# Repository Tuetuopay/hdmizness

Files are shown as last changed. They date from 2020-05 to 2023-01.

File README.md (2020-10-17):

# hdmizness

A business card that runs Linux and that has an HDMI output.

## Project layout

```
.
+- documentation       - docs for various chips and boards used
+- graphics            - various graphic files used for the hardware design
+- hardware            - home of the hardware design files
|  `- licheedmi        - PoC board that leverages a Lichee Pi Nano to test the concept
|                        of a pcb-only hdmi female connector
`- software            - everything related to the software running on those boards
```

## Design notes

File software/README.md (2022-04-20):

# HDMIzness software

The business card runs a plain Buildroot build, with proper patches.

## Compiling

You need a working compiler, along with the required deps for a buildroot build. On Debian 11 this
would be:

- build-essentials
- rsync

The following commands assume you are in the current directory (`software/` from the root of the
repo):

```
# Download buildroot
git submodule update --init

# Create config (ignore warnings about the Doom WAD)
make -C buildroot BR2_EXTERNAL=.. hdmizness_defconfig

# Build
make -C buildroot BR2_EXTERNAL=.. -j$(nproc)
```

A full build takes 30 minutes on a Xeon E-2246G.

Build artifacts are now present in `buildroot/output/images`, with a full image ready to be flashed
on the card as `buildroot/output/images/flash.bin`.

## Flashing

Programming the card is done over USB with Allwinner's FEL mode. The tool to flash has been built
by buildroot, and is present in the host tool directory (`buildroot/output/host/bin`) as
`sunxi-fel`.

First, the card needs to be put in FEL mode.

- If it has not been programmed before, it will boot to FEL mode once powered up.
- If it already has a working image, it needs to "fail" to boot. The easiest way is to short one of
  the SPI pins of the flash to ground (a simple DuPont jumper works fine), and to press the onboard
  Reset button. The SoC will fail to read the flash, and fallback to FEL mode.

FEL can be confirmed by listing the USB devices:

```
$ lsusb -d 1f3a:efe8
Bus 001 Device 018: ID 1f3a:efe8 Allwinner Technology sunxi SoC OTG connector in FEL/flashing mode
```

With FEL found, the card can be flashed using `sunxi-fel` (note that it needs to be run as root,
unless udev rules have been setup):

```
# buildroot/output/host/bin/sunxi-fel -v -p spiflash-write 0 buildroot/output/images/flash.bin
```

Once finished, reset the card with the onboard button. After a few seconds, the onboard LED should
switch from a solid red to a solid blue (v1 with NXP TDA HDMI transmitter) or green (v2 with Lattice
SiI HDMI transmitter). Then, it should turn white to indicate a successful Linux boot.

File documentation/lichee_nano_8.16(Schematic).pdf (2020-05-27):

LCD | DDR | CSI

## SDC0

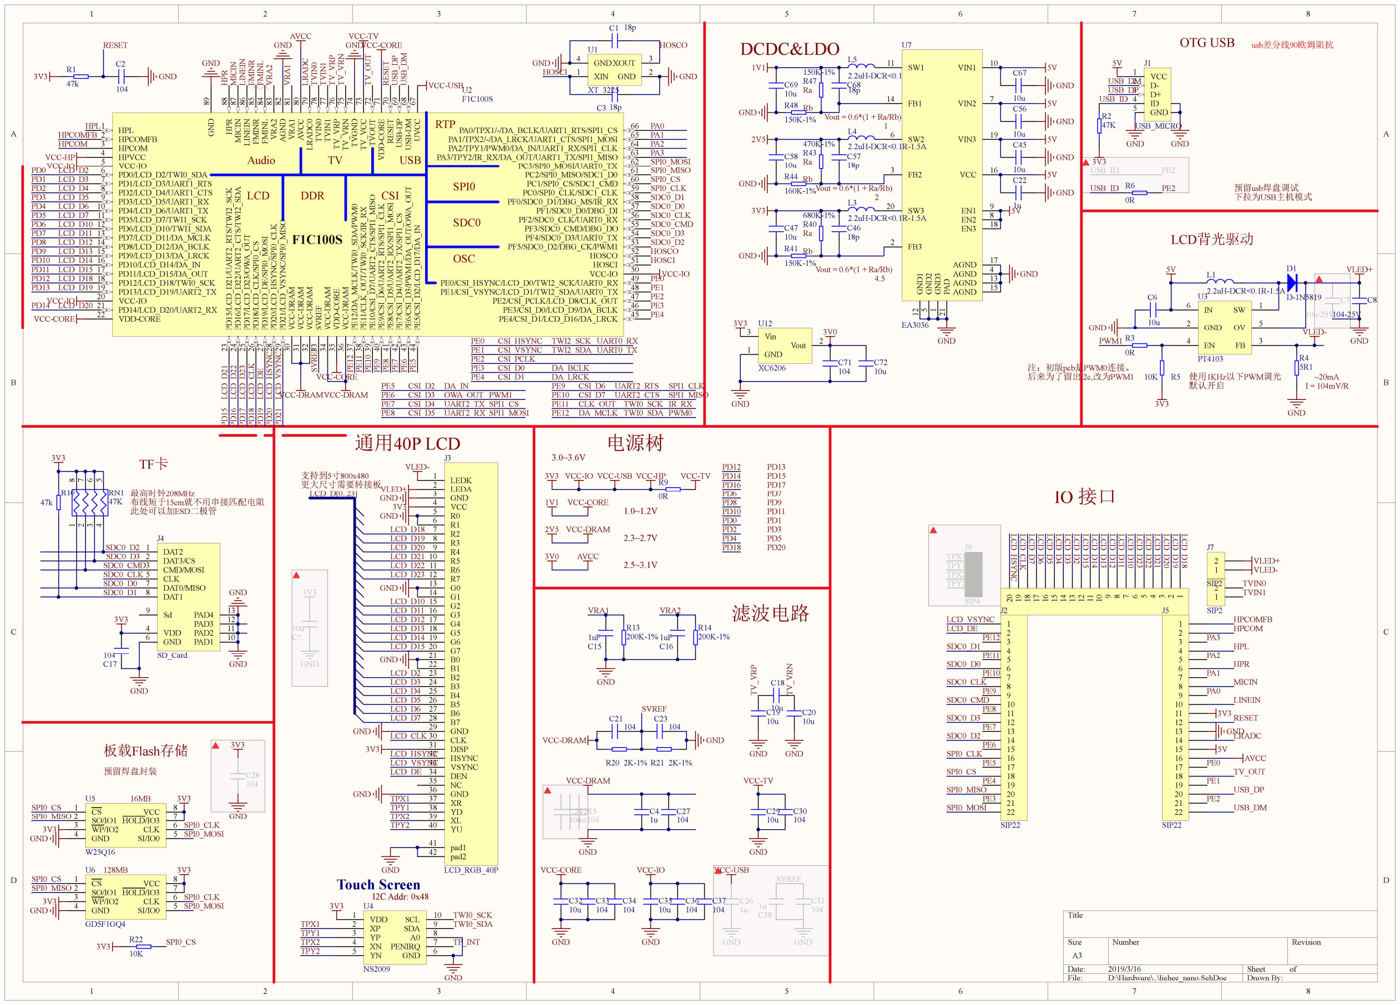
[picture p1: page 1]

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
Title

Size | Number | | Revision
A3
Date: | 2019/3/16 | Sheet | of
File: | D:\Hardware\..\lichee_nano.SchDoc | Drawn By:

HPL 1
HPCOMFB 2
HPCOM 3
HPVCC 4
VCC-IO 5
PD0/LCD_D2/TWI0_SDA 6
PD1/LCD_D3/UART1_RTS 7
PD2/LCD_D4/UART1_CTS 8
PD3/LCD_D5/UART1_RX 9
PD4/LCD_D6/UART1_TX 10
PD5/LCD_D7/TWI1_SCK 11
PD6/LCD_D10/TWI1_SDA 12
PD7/LCD_D11/DA_MCLK 13
PD8/LCD_D12/DA_BCLK 14
PD9/LCD_D13/DA_LRCK 15
PD10/LCD_D14/DA_IN 16
PD11/LCD_D15/DA_OUT 17
PD12/LCD_D18/TWI0_SCK 18
PD13/LCD_D19/UART2_TX 19
VCC-IO 20
PD14/LCD_D20/UART2_RX 21
VDD-CORE 22 | PD¹⁵/LCD_D²¹/UART²_RTS/TWI2_SCK 23 PD¹⁶/LCD_D²²/UART²_CTS/TWI2_SDA 24 PD¹⁷/LCD_D²³/OWA_OUT 25 PD¹⁸/LCD_CLK/SPI0_CS 26 PD¹⁹/LCD_DE/SPI0_MOSI 27 PD²⁰/LCD_HSYNC/SPI0_CLK 28 PD²¹/LCD_VSYNC/SPI0_MISO 29 VCC⁻DRAM 30 VCC⁻DRAM 31 VCC⁻DRAM 32 SVREF 33 VCC⁻DRAM 34 VDD⁻CORE 35 VCC⁻DRAM 36 PE¹²/DA_MCLK/TWI0_SDA/PWM⁰ 37 PE¹¹/CLK_OUT/TWI0_SCK/IR_RX 38 PE¹⁰/CSI_D⁷/UART²_CTS/SPI1_MISO 39 PE⁹/CSI_D⁶/UART²_RTS/SPI1_CLK 40 PE⁸/CSI_D⁵/UART²_RX/SPI1_MOSI 41 PE⁷/CSI_D⁴/UART²_TX/SPI1_CS 42 PE⁶/CSI_D³/PWM¹/DA_OUT/OWA_OUT 43 PE⁵/CSI_D²/LCD_D¹⁷/DA_IN 44
PE4/CSI_D1/LCD_D16/DA_LRCK | 45 PE3/CSI_D0/LCD_D9/DA_BCLK | 46 PE2/CSI_PCLK/LCD_D8/CLK_OUT | 47 PE1/CSI_VSYNC/LCD_D1/TWI2_SDA/UART0_TX | 48 PE0/CSI_HSYNC/LCD_D0/TWI2_SCK/UART0_RX | 49 VCC-IO | 50 HOSCI | 51 HOSCO | 52 PF5/SDC0_D2/DBG_CK/PWM1 | 53 PF4/SDC0_D3/UART0_TX | 54 PF3/SDC0_CMD/DBG_DO | 55 PF2/SDC0_CLK/UART0_RX | 56 PF1/SDC0_D0/DBG_DI | 57 PF0/SDC0_D1/DBG_MS/IR_RX | 58 PC0/SPI0_CLK/SDC1_CLK | 59 PC1/SPI0_CS/SDC1_CMD | 60 PC2/SPI0_MISO/SDC1_D0 | 61 PC3/SPI0_MOSI/UART0_TX | 62 PA3/TPY2/IR_RX/DA_OUT/UART1_TX/SPI1_MISO | 63 PA2/TPY1/PWM0/DA_IN/UART1_RX/SPI1_CLK | 64 PA1/TPX2/-/DA_LRCK/UART1_CTS/SPI1_MOSI | 65 PA0/TPX1/-/DA_BCLK/UART1_RTS/SPI1_CS | 66 UVCC ⁶⁷ USB⁻DM ⁶⁸ USB⁻DP ⁶⁹ RESET ⁷⁰ VDD⁻CORE ⁷¹ TVOUT ⁷² TV_VCC ⁷³ TVGND ⁷⁴ TV_VRN ⁷⁵ TV_VRP ⁷⁶ TVIN¹ ⁷⁷ TVIN⁰ ⁷⁸ LRADC⁰ ⁷⁹ AVCC ⁸⁰ VRA¹ ⁸¹ AGND ⁸² VRA² ⁸³ FMINL ⁸⁴ FMINR ⁸⁵ LINEIN ⁸⁶ MICIN ⁸⁷ HPR ⁸⁸ GND ⁸⁹

## OSC

## SPI0

## RTP

Audio | TV | USB

## F1C100S

U2
F1C100S

LEDK 1
LEDA 2
GND 3
VCC 4
R0 5
R1 6
R2 7
R3 8
R4 9
R5 10
R6 11
R7 12
G0 13
G1 14
G2 15
G3 16
G4 17
G5 18
G6 19
G7 20
B0 21
B1 22
B2 23
B3 24
B4 25
B5 26
B6 27
B7 28
GND 29
CLK 30
DISP 31
HSYNC 32
VSYNC 33
DEN 34
NC 35
GND 36
XR 37
YD 38
XL 39
YU 40

pad1 41
pad2 42

J3

LCD_RGB_40P

LCD_D2
LCD_D3
LCD_D4
LCD_D5
LCD_D6
LCD_D7

LCD_D10
LCD_D11
LCD_D12
LCD_D13
LCD_D14
LCD_D15

LCD_D18
LCD_D19
LCD_D20
LCD_D21
LCD_D22
LCD_D23

LCD_D[0..23] GND

3V3

GND

C?

10u

LCD_CLK

LCD_DE

LCD_HSYNC
LCD_VSYNC

TPX1

TPX2

TPY1

TPY2

GND

GND

VLED+

VLED-

# 通用40P LCD

GND

GND

GND

3V3

3V3

GND

支持到5寸800x480
更大尺寸需要转接板

LCD_D2
LCD_D3
LCD_D4
LCD_D5
LCD_D6
LCD_D7
LCD_D10
LCD_D11
LCD_D12
LCD_D13
LCD_D14
LCD_D15
LCD_D18
LCD_D19
LCD_D20 | LCD_D²¹ LCD_D²² LCD_D²³ LCD_CLK LCD_DE LCD_HSYNC LCD_VSYNC

VCC-IO

VCC-IO

VCC-IO

VCC-CORE

VCC-CORE

VCC-DRAMVCC-DRAM SVREF

VCC-CORE RESET USB_DP USB_DMGND

VCC-HP

HPL | HPR MICIN LINEIN FMINR FMINL VRA² | VRA¹ AVCCLRADC TVIN⁰ TVIN¹ TV_VRP TV_VRN

VCC-TVTV_OUT

PE0
PE1
PE2
PE3

PE4 PE¹² PE¹¹ PE¹⁰ PE⁹ PE⁸ PE⁷ PE⁶ PE⁵

HOSCO
HOSCI

SDC0_D0

SDC0_D1

SDC0_D2

SDC0_D3

SDC0_CLK
SDC0_CMD

SPI0_CLK

SPI0_CS

SPI0_MISO

SPI0_MOSI

HPCOMFB
HPCOM
XIN 1 | GND | 2
XOUT | 3 GND 4

U1

XT_3225

GND
GND

C3 18p

C1 18p

HOSCO

HOSCI

SDC0_CMD
SDC0_CLK
SDC0_D0
SDC0_D1

SDC0_D2
SDC0_D3

GND

GND

3V3

C17

104 ¹

2

34 58
7

6
RN1
47K

R10
47k

3V3

最高时钟208MHz
布线短于15cm就不用串接匹配电阻
此处可以加ESD二极管

## TF卡

GND

CS 1
SO/IO1 2
WP/IO2 3
GND 4 | SI/IO0 | 5
| CLK | 6
HOLD/IO3 | 7
VCC | 8

U5

W25Q16

SPI0_MISO

SPI0_MOSI

SPI0_CLK

SPI0_CS

CS 1
SO/IO1 2
WP/IO2 3
GND 4 | SI/IO0 | 5
| CLK | 6
HOLD/IO3 | 7
VCC | 8

U6

GD5F1GQ4

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
3V3 | SPI0_CS

16MB

128MB

## 板载Flash存储

预留焊盘封装

# DCDC&LDO

SW 1

GND 2

FB | 3 EN 4
OV | 5

IN 6

U3

PT4103

L1
2.2uH-DCR<0.1R-1.5A
C6

10u GND

D1

D-1N5819 C7

10u-25V

C8

| 104-25V VLED+

GND

10K R5
I = 104mV/R

R4
5R1

GND

VLED-

使用1KHz以下PWM调光 | ~20mA

## LCD背光驱动

5V

PWM1 R3
0R

R2
47K

usb差分线90欧姆阻抗

VCC 1
D- 2
D+ 3
ID 4
GND 5

J1

USB_MICRO

GND GND

USB_ID

预留usb焊盘调试
下拉为USB主机模式

# 电源树

3V3 VCC-IO

GND | GND

VCC-TV

1V1 VCC-CORE
1.0~1.2V

3.0~3.6V

VCC-USB

VCC-USB

2V5 VCC-DRAM
2.3~2.7V

3V0 AVCC
2.5~3.1V

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
PD10
PD11
PD12
PD13
PD14 | PD¹⁵ PD¹⁶ PD¹⁷ PD¹⁸ PD¹⁹ PD²⁰ PD²¹
PD0 | PD1
PD2 | PD3
PD4 | PD5
PD6 | PD7
PD8 | PD9
PD10 | PD11
PD12 | PD13
PD14 | PD15
PD16 | PD17

C2

104

3V3 | GND

RESET

GND

C15

1uF

R13
200K-1%
VRA1 | VRA2

C16

1uF

R14
200K-1%

R20 2K-1% R21 2K-1%

C21
104

C23
104
VCC-DRAM | GND

SVREF

SVREF

C31
104 C38

1u

GND

VCC-DRAM

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
VCC-CORE

C32
10u

C33
104

C34
104

GND

VCC-IO

C35
10u

C36
104

C37
104

GND

VCC-TV

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
GND | GND TV_VRP | TV_VRN

## OTG USB

# 滤波电路

# IO 接口

USB_DP

USB_DM

VCC-HP

R1
47k

R9
0R

SPI0_MISO

SPI0_MOSI

SPI0_CLK

SPI0_CS

1V1 | 5V

L5

# 2.2uH-DCR<0.1R-1.5A GND³

1

FB3 2

FB2 3

AGND 4 GND²

5

SW2 6

VIN2 | 7
EN2 | 8
EN1 | 9
VIN1 | 10 SW1 11 | GND¹ 12
AGND | 13

FB1 14

AGND | 15
VCC | 16
AGND | 17
EN3 | 18
VIN3 | 19
SW3 20 | PAD 21

U7

EA3036

R47

150K-1%
GND

C67

10u

C68 18p C69
10u Ra
5V Rb GND
GND Vout = 0.6*(1 + Ra/Rb)

C56

10u

R48
150K-1%
1
2V5 | 5V

L4
2.2uH-DCR<0.1R-1.5A
R43

470K-1%
GND

C45

10u

C57
18p

C58
10u Ra
5V Rb GND | Vout = 0.6*(1 + Ra/Rb) | GND
C22

1u

R44
160K-1%
2
3V3 | 5V

L3
2.2uH-DCR<0.1R-1.5A
R40

680K-1%
C46
18p

C47
10u Ra

Rb GND

R41
150K-1%
GND Vout = 0.6*(1 + Ra/Rb) 4.5

GND

3V0

C71
104

Vin 3

GND 1

Vout 2

U12

XC6206

3V3

C72
10u

GND

C26
1u

GND

VCC-USB

3V3

C28
104

GND

3V3 20 | 119 | 218 | 317 | 416 | 515 | 614 | 713 | 812 | 91110

J8

# SIP20LCD_HSYNC LCD_CLK

LCD_DE

LCD_VSYNC | LCD_D7 LCD_D6 LCD_D5 LCD_D4 LCD_D3 LCD_D2 LCD_D15 LCD_D14 LCD_D13 LCD_D12 LCD_D11 LCD_D10 LCD_D23 LCD_D22 LCD_D21 LCD_D20 LCD_D19 LCD_D18 PD18 | PD20

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
PE10
PE11
PE12

CSI_HSYNC TWI2_SCK UART0_RX CSI_VSYNC TWI2_SDA UART0_TX CSI_PCLK
CSI_D0
CSI_D1
CSI_D2
CSI_D3
CSI_D4
CSI_D5

CSI_D6
CSI_D7

DA_MCLK

CLK_OUT

DA_BCLK
DA_LRCK
DA_IN
OWA_OUT
UART2_TX SPI1_CS
UART2_RX SPI1_MOSI

UART2_RTS SPI1_CLK
UART2_CTS SPI1_MISO
TWI0_SCK
TWI0_SDA

IR_RX
PWM0

3V3

默认开启

PA0
PA1
PA2
PA3

USB_ID R6
0R

PE2

USB_ID | PE2

PE5

PE6

PE7

PE8

PE9

PE10

PE11

PE12

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
SDC0_D0

SDC0_D1

SDC0_D2

SDC0_D3

SDC0_CLK

SDC0_CMD

SPI0_CLK

SPI0_CS

SPI0_MISO

SPI0_MOSI

HPL

HPCOMFB
HPCOM

RESET

USB_DP

USB_DM

HPR

MICIN

LINEIN

AVCC

LRADC

TVIN0
TVIN1

TV_OUT

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
SIP22

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
SIP22

DAT2 1
DAT3/CS 2
CMD/MOSI 3

VDD 4

CLK 5

GND 6

DAT0/MISO 7
DAT1 8

Sd 9

PAD1 | 10 PAD2 | 11 PAD3 | 12 PAD4 | 13

J4

SD_Card

1

2

J6

SIP2

1

2

J7

SIP2

VLED+
VLED-

1

2

3

4

J9

SIP4

TPX1

TPX2

TPY1

TPY2

PWM1

注：初版pcb是PWM0连接。
后来为了留出i2c,改为PWM1

# Touch Screen

TP_INT

I2C Addr: 0x48

VDD 1
XP 2
YP 3
XN 4
YN 5 | GND | 6
| PENIRQ | 7
| A0 | 8
SDA | 9
SCL | 10

U4

NS2009

3V3

TPX1
TPY1
TPX2

GND

TPY2

TWI0_SCK
TWI0_SDA

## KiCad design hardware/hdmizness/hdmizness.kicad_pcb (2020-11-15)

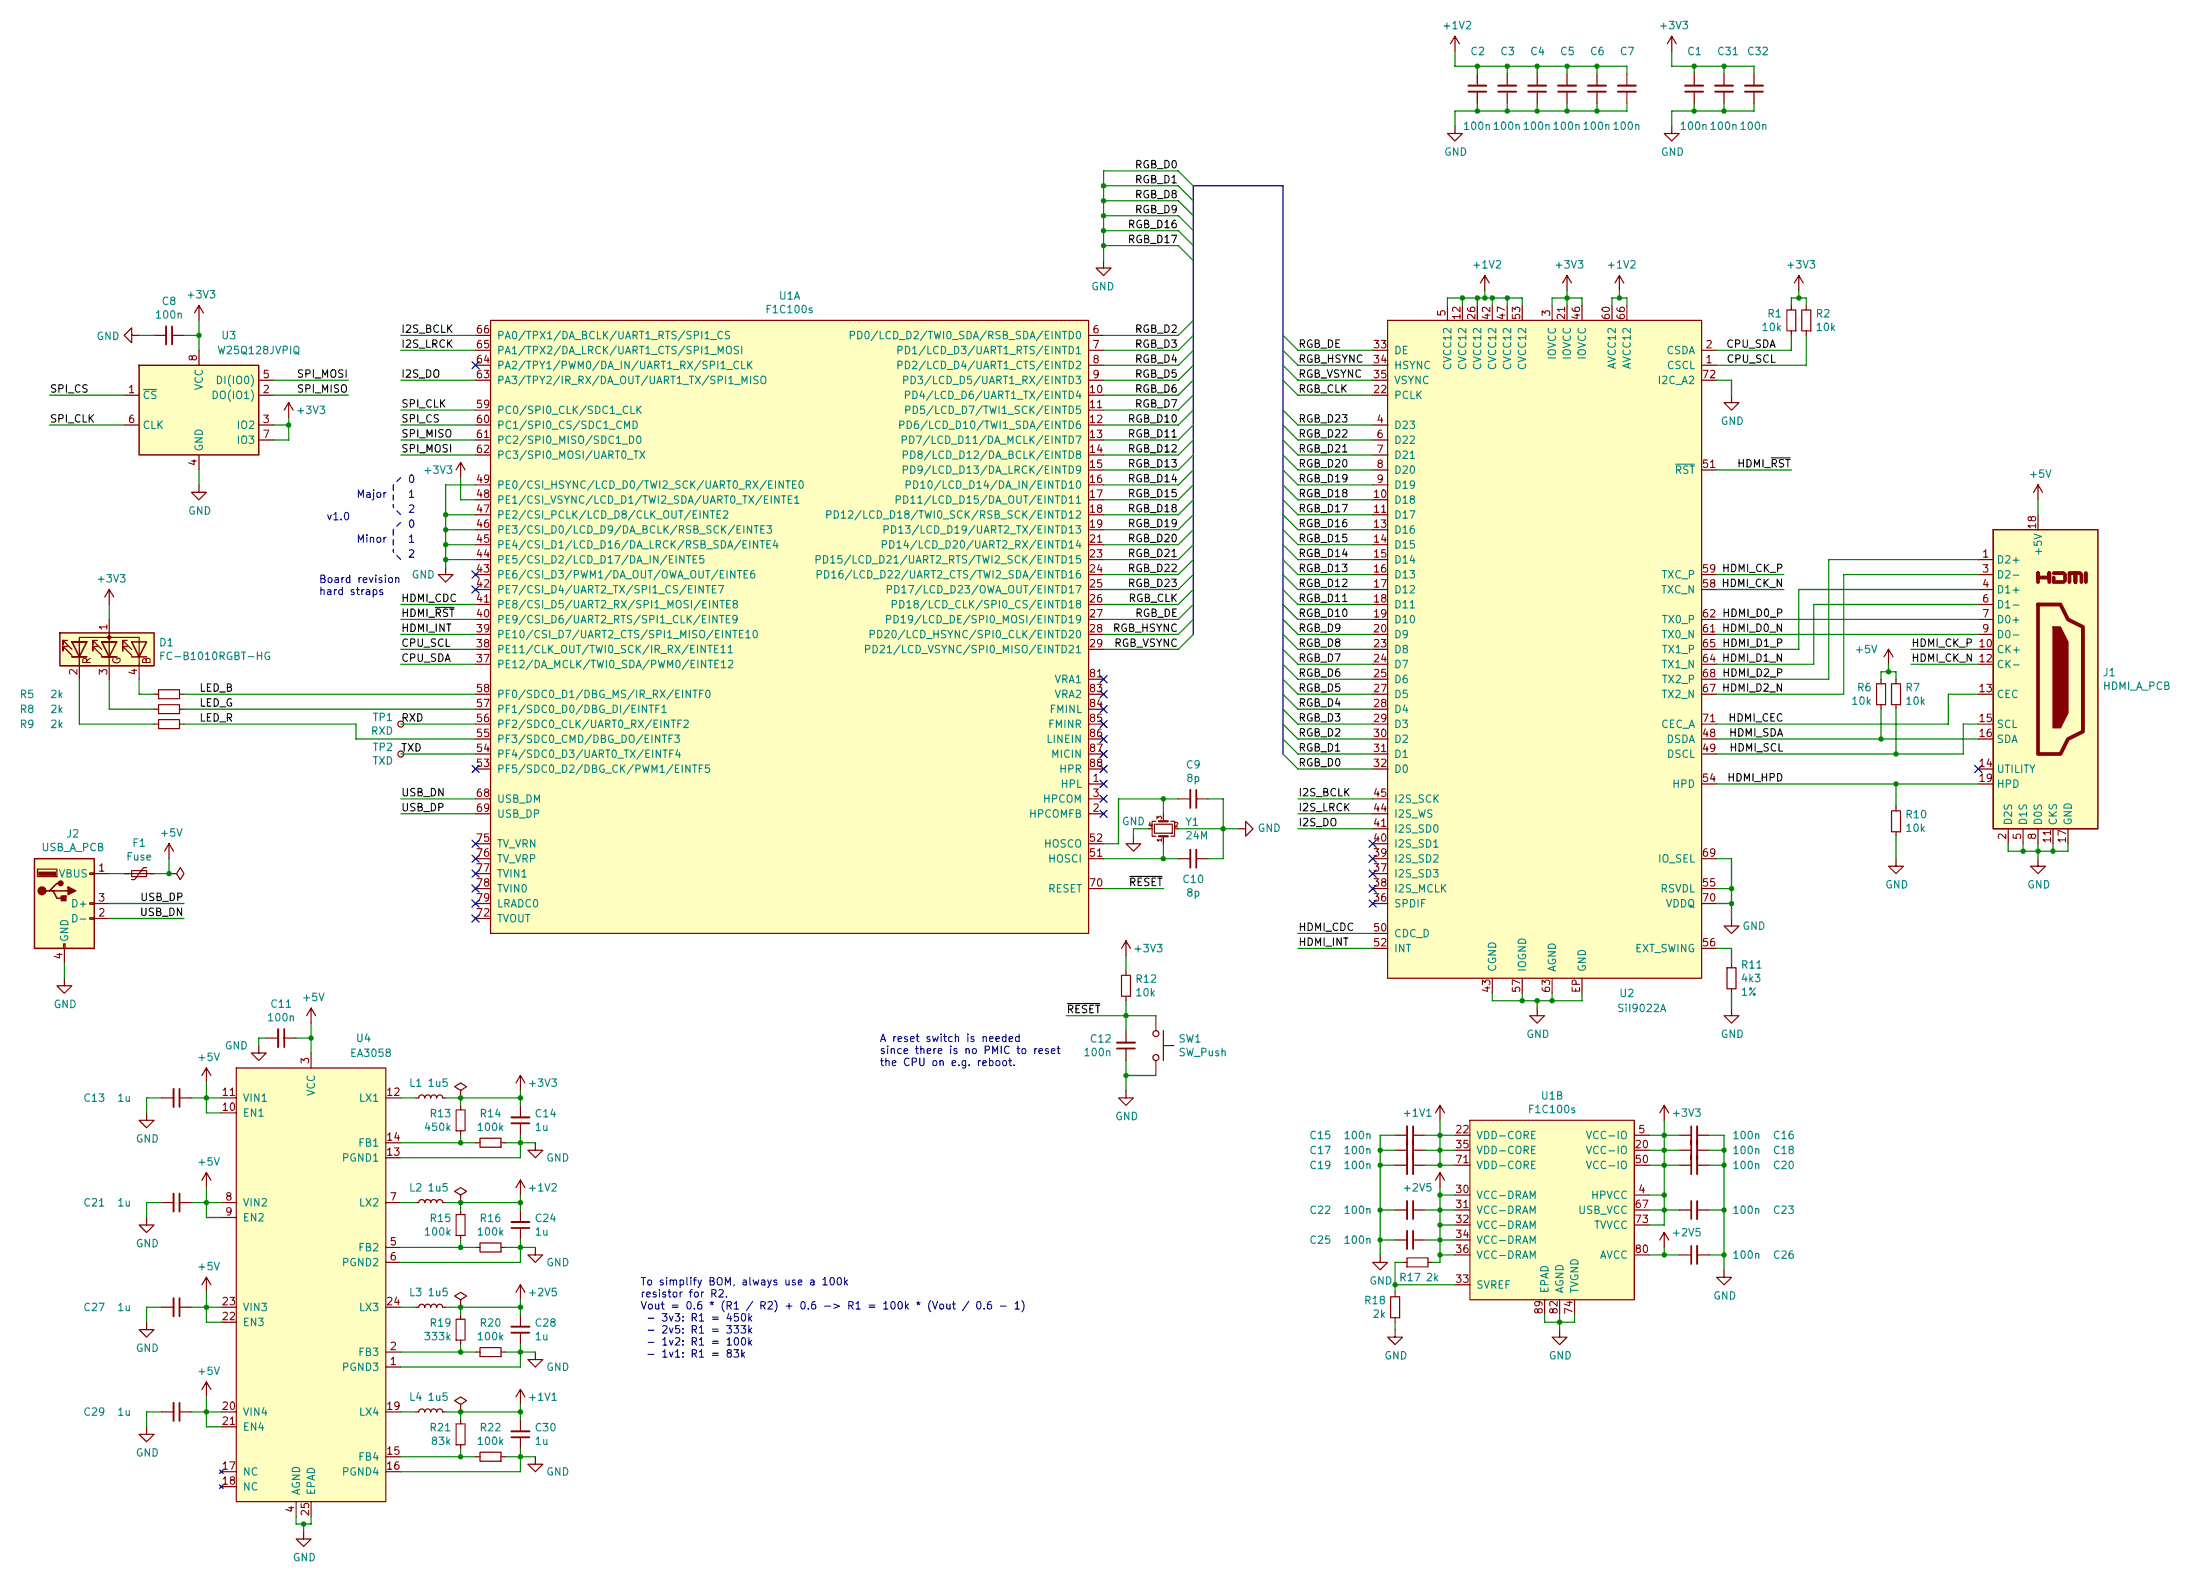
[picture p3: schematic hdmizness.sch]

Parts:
C1, C2, C3, C4, C5, C6, C7, C8, C11, C12, C15, C16, C17, C18, C19, C20, C22, C23, C25, C26, C31, C32: 100n; C_0402_1005Metric; MFR P/N CL05B104KO5NNNC; LCSC P/N C1525
C9, C10: 8p; C_0402_1005Metric; MFR P/N CL05C080CB5NNNC; LCSC P/N C318586
C13, C14, C21, C24, C27, C28, C29, C30: 1u; C_0402_1005Metric; MFR P/N CL05A105KQ5NNNC; LCSC P/N C107372
D1: FC-B1010RGBT-HG; PLCC1010
F1: Fuse; Fuse_0603_1608Metric; MFR P/N 06H1100D; LCSC P/N C182303
J1: HDMI_A_PCB
J2: USB_A_PCB
L1, L2, L3, L4: 1u5; L_Vishay_IHHP-0806; MFR P/N CIGT201610UM1R5MNE; LCSC P/N C307630
R1, R2, R6, R7, R10, R12: 10k; R_0402_1005Metric; MFR P/N CR-02FL6---10K; LCSC P/N C406733
R5, R8, R9, R17, R18: 2k; R_0402_1005Metric; MFR P/N RC-02W2001FT; LCSC P/N C304583
R11: 4k3; R_0402_1005Metric; Tolerance 1%; MFR P/N CR-02FL6---10K; LCSC P/N C406733
R13: 450k; R_0402_1005Metric; MFR P/N 0402WGF4503TCE; LCSC P/N C407681
R14, R16, R20, R22: 100k; R_0402_1005Metric; MFR P/N RC-02W1003FT; LCSC P/N C258090
R15: 100k; R_0402_1005Metric; MFR P/N WR04X2003FTL; LCSC P/N C305297
R19: 333k; R_0402_1005Metric; MFR P/N WR04X3323FTL; LCSC P/N C172051
R21: 83k; R_0402_1005Metric; MFR P/N RC-02W8202FT; LCSC P/N C304638
SW1: SW_Push; 1TS028A-2400-0603-CT; MFR P/N 1TS028A-2400-0603-CT; LCSC P/N C481994
TP1: RXD; TestPoint_Pad_1.0x1.0mm
TP2: TXD; TestPoint_Pad_1.0x1.0mm
U1: F1C100s; QFN-88_EP_10x10_Pitch0.4mm
U2: SiI9022A; QFN-72-1EP_10x10mm_P0.5mm_EP4.7x4.7mm_ThermalVias
U3: W25Q128JVPIQ; WSON-8-1EP_6x5mm_P1.27mm_EP3.4x4.3mm; MFR P/N W25Q128JVPIQ; LCSC P/N C190862
U4: EA3058; QFN-24-1EP_4x4mm_P0.5mm_EP2.6x2.6mm; MFR P/N EA3058QDR; LCSC P/N C575412
Y1: 24M; Crystal_SMD_2016-4Pin_2.0x1.6mm; MFR P/N CN4024M00009T8188011; LCSC P/N C708986

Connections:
+1V1: C15.1, C17.1, C19.1, C30.2, L4.2, R21.2, U1.22 (VDD-CORE), U1.35 (VDD-CORE), U1.71 (VDD-CORE)
+1V2: C2.2, C3.2, C4.2, C5.2, C6.2, C7.2, C24.2, L2.2, R15.2, U2.5 (CVCC12), U2.12 (CVCC12), U2.26 (CVCC12), U2.42 (CVCC12), U2.47 (CVCC12), U2.53 (CVCC12), U2.60 (AVCC12), U2.66 (AVCC12)
+2V5: C22.1, C25.1, C26.1, C28.2, L3.2, R17.2, R19.2, U1.30 (VCC-DRAM), U1.31 (VCC-DRAM), U1.32 (VCC-DRAM), U1.34 (VCC-DRAM), U1.36 (VCC-DRAM), U1.80 (AVCC)
+3V3: C1.2, C8.1, C14.2, C16.1, C18.1, C20.1, C23.1, C31.2, C32.2, D1.1 (A), L1.2, R1.2, R2.2, R12.2, R13.2, U1.4 (HPVCC), U1.5 (VCC-IO), U1.20 (VCC-IO), U1.48 (PE1/CSI_VSYNC/LCD_D1/TWI2_SDA/UART0_TX/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), U1.50 (VCC-IO), U1.67 (USB_VCC), U1.73 (TVVCC), U2.3 (IOVCC), U2.21 (IOVCC), U2.46 (IOVCC), U3.3 (IO2), U3.7 (IO3), U3.8 (VCC)
+5V: C11.1, C13.1, C21.1, C27.1, C29.1, F1.1, J1.18 (+5V), R6.2, R7.2, U4.3 (VCC), U4.8 (VIN2), U4.9 (EN2), U4.10 (EN1), U4.11 (VIN1), U4.20 (VIN4), U4.21 (EN4), U4.22 (EN3), U4.23 (VIN3)
/CPU_SCL: R2.1, U1.38 (PE11/CLK_OUT/TWI0_SCK/IR_RX/EINTE11), U2.1 (CSCL)
/CPU_SDA: R1.1, U1.37 (PE12/DA_MCLK/TWI0_SDA/PWM0/EINTE12), U2.2 (CSDA)
/HDMI_CDC: U1.41 (PE8/CSI_D5/UART2_RX/SPI1_MOSI/EINTE8), U2.50 (CDC_D)
/HDMI_CEC: J1.13 (CEC), U2.71 (CEC_A)
/HDMI_CK_N: J1.12 (CK-), U2.58 (TXC_N)
/HDMI_CK_P: J1.10 (CK+), U2.59 (TXC_P)
/HDMI_D0_N: J1.9 (D0-), U2.61 (TX0_N)
/HDMI_D0_P: J1.7 (D0+), U2.62 (TX0_P)
/HDMI_D1_N: J1.6 (D1-), U2.64 (TX1_N)
/HDMI_D1_P: J1.4 (D1+), U2.65 (TX1_P)
/HDMI_D2_N: J1.3 (D2-), U2.67 (TX2_N)
/HDMI_D2_P: J1.1 (D2+), U2.68 (TX2_P)
/HDMI_HPD: J1.19 (HPD), R10.2, U2.54 (HPD)
/HDMI_INT: U1.39 (PE10/CSI_D7/UART2_CTS/SPI1_MISO/EINTE10), U2.52 (INT)
/HDMI_SCL: J1.15 (SCL), R7.1, U2.49 (DSCL)
/HDMI_SDA: J1.16 (SDA), R6.1, U2.48 (DSDA)
/HDMI_~RST: U1.40 (PE9/CSI_D6/UART2_RTS/SPI1_CLK/EINTE9), U2.51 (~RST)
/I2S_BCLK: U1.66 (PA0/TPX1/DA_BCLK/UART1_RTS/SPI1_CS), U2.45 (I2S_SCK)
/I2S_DO: U1.63 (PA3/TPY2/IR_RX/DA_OUT/UART1_TX/SPI1_MISO), U2.41 (I2S_SD0)
/I2S_LRCK: U1.65 (PA1/TPX2/DA_LRCK/UART1_CTS/SPI1_MOSI), U2.44 (I2S_WS)
/LED_B: R5.2, U1.58 (PF0/SDC0_D1/DBG_MS/IR_RX/EINTF0)
/LED_G: R8.2, U1.57 (PF1/SDC0_D0/DBG_DI/EINTF1)
/LED_R: R9.2, U1.55 (PF3/SDC0_CMD/DBG_DO/EINTF3)
/RGB_CLK: U1.26 (PD18/LCD_CLK/SPI0_CS/EINTD18), U2.22 (PCLK)
/RGB_D2: U1.6 (PD0/LCD_D2/TWI0_SDA/RSB_SDA/EINTD0), U2.30 (D2)
/RGB_D3: U1.7 (PD1/LCD_D3/UART1_RTS/EINTD1), U2.29 (D3)
/RGB_D4: U1.8 (PD2/LCD_D4/UART1_CTS/EINTD2), U2.28 (D4)
/RGB_D5: U1.9 (PD3/LCD_D5/UART1_RX/EINTD3), U2.27 (D5)
/RGB_D6: U1.10 (PD4/LCD_D6/UART1_TX/EINTD4), U2.25 (D6)
/RGB_D7: U1.11 (PD5/LCD_D7/TWI1_SCK/EINTD5), U2.24 (D7)
/RGB_D10: U1.12 (PD6/LCD_D10/TWI1_SDA/EINTD6), U2.19 (D10)
/RGB_D11: U1.13 (PD7/LCD_D11/DA_MCLK/EINTD7), U2.18 (D11)
/RGB_D12: U1.14 (PD8/LCD_D12/DA_BCLK/EINTD8), U2.17 (D12)
/RGB_D13: U1.15 (PD9/LCD_D13/DA_LRCK/EINTD9), U2.16 (D13)
/RGB_D14: U1.16 (PD10/LCD_D14/DA_IN/EINTD10), U2.15 (D14)
/RGB_D15: U1.17 (PD11/LCD_D15/DA_OUT/EINTD11), U2.14 (D15)
/RGB_D18: U1.18 (PD12/LCD_D18/TWI0_SCK/RSB_SCK/EINTD12), U2.10 (D18)
/RGB_D19: U1.19 (PD13/LCD_D19/UART2_TX/EINTD13), U2.9 (D19)
/RGB_D20: U1.21 (PD14/LCD_D20/UART2_RX/EINTD14), U2.8 (D20)
/RGB_D21: U1.23 (PD15/LCD_D21/UART2_RTS/TWI2_SCK/EINTD15), U2.7 (D21)
/RGB_D22: U1.24 (PD16/LCD_D22/UART2_CTS/TWI2_SDA/EINTD16), U2.6 (D22)
/RGB_D23: U1.25 (PD17/LCD_D23/OWA_OUT/EINTD17), U2.4 (D23)
/RGB_DE: U1.27 (PD19/LCD_DE/SPI0_MOSI/EINTD19), U2.33 (DE)
/RGB_HSYNC: U1.28 (PD20/LCD_HSYNC/SPI0_CLK/EINTD20), U2.34 (HSYNC)
/RGB_VSYNC: U1.29 (PD21/LCD_VSYNC/SPI0_MISO/EINTD21), U2.35 (VSYNC)
/RXD: TP1.1, U1.56 (PF2/SDC0_CLK/UART0_RX/EINTF2)
/SPI_CLK: U1.59 (PC0/SPI0_CLK/SDC1_CLK), U3.6 (CLK)
/SPI_CS: U1.60 (PC1/SPI0_CS/SDC1_CMD), U3.1 (~CS)
/SPI_MISO: U1.61 (PC2/SPI0_MISO/SDC1_D0), U3.2 (DO(IO1))
/SPI_MOSI: U1.62 (PC3/SPI0_MOSI/UART0_TX), U3.5 (DI(IO0))
/TXD: TP2.1, U1.54 (PF4/SDC0_D3/UART0_TX/EINTF4)
/USB_DN: J2.2 (D-), U1.68 (USB_DM)
/USB_DP: J2.3 (D+), U1.69 (USB_DP)
/~RESET: C12.2, R12.1, SW1.1, U1.70 (RESET)
GND: C1.1, C2.1, C3.1, C4.1, C5.1, C6.1, C7.1, C8.2, C9.1, C10.1, C11.2, C12.1, C13.2, C14.1, C15.2, C16.2, C17.2, C18.2, C19.2, C20.2, C21.2, C22.2, C23.2, C24.1, C25.2, C26.2, C27.2, C28.1, C29.2, C30.1, C31.1, C32.1, J1.2 (D2S), J1.5 (D1S), J1.8 (D0S), J1.11 (CKS), J1.17 (GND), J2.4 (GND), R10.1, R11.2, R14.1, R16.1, R18.1, R20.1, R22.1, SW1.2, U1.44 (PE5/CSI_D2/LCD_D17/DA_IN/EINTE5), U1.45 (PE4/CSI_D1/LCD_D16/DA_LRCK/RSB_SDA/EINT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), U1.46 (PE3/CSI_D0/LCD_D9/DA_BCLK/RSB_SCK/EINTE3), U1.47 (PE2/CSI_PCLK/LCD_D8/CLK_OUT/EINTE2), U1.49 (PE0/CSI_HSYNC/LCD_D0/TWI2_SCK/UART0_RX/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), U1.74 (TVGND), U1.82 (AGND), U1.89 (EPAD), U2.11 (D17), U2.13 (D16), U2.20 (D9), U2.23 (D8), U2.31 (D1), U2.32 (D0), U2.43 (CGND), U2.55 (RSVDL), U2.57 (IOGND), U2.63 (AGND), U2.69 (IO_SEL), U2.70 (VDDQ), U2.72 (I2C_A2), U2.73, U2.EP (GND), U3.4 (GND), U4.1 (PGND3), U4.4 (AGND), U4.6 (PGND2), U4.13 (PGND1), U4.16 (PGND4), U4.25 (EPAD), Y1.2, Y1.4
unnamed: C9.2, U1.52 (HOSCO), Y1.3
unnamed: C10.2, U1.51 (HOSCI), Y1.1
unnamed: D1.2 (RK), R9.1
unnamed: D1.3 (GK), R8.1
unnamed: D1.4 (BK), R5.1
unnamed: F1.2, J2.1 (VBUS)
unnamed: L1.1, U4.12 (LX1)
unnamed: L2.1, U4.7 (LX2)
unnamed: L3.1, U4.24 (LX3)
unnamed: L4.1, U4.19 (LX4)
unnamed: R11.1, U2.56 (EXT_SWING)
unnamed: R13.1, R14.2, U4.14 (FB1)
unnamed: R15.1, R16.2, U4.5 (FB2)
unnamed: R17.1, R18.2, U1.33 (SVREF)
unnamed: R19.1, R20.2, U4.2 (FB3)
unnamed: R21.1, R22.2, U4.15 (FB4)

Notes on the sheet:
To simplify BOM, always use a 100k resistor for R2. Vout = 0.6 * (R1 / R2) + 0.6 -> R1 = 100k * (Vout / 0.6 - 1) - 3v3: R1 = 450k - 2v5: R1 = 333k - 1v2: R1 = 100k - 1v1: R1 = 83k
A reset switch is needed since there is no PMIC to reset the CPU on e.g. reboot.
Major
Minor
Board revision hard straps
v1.0

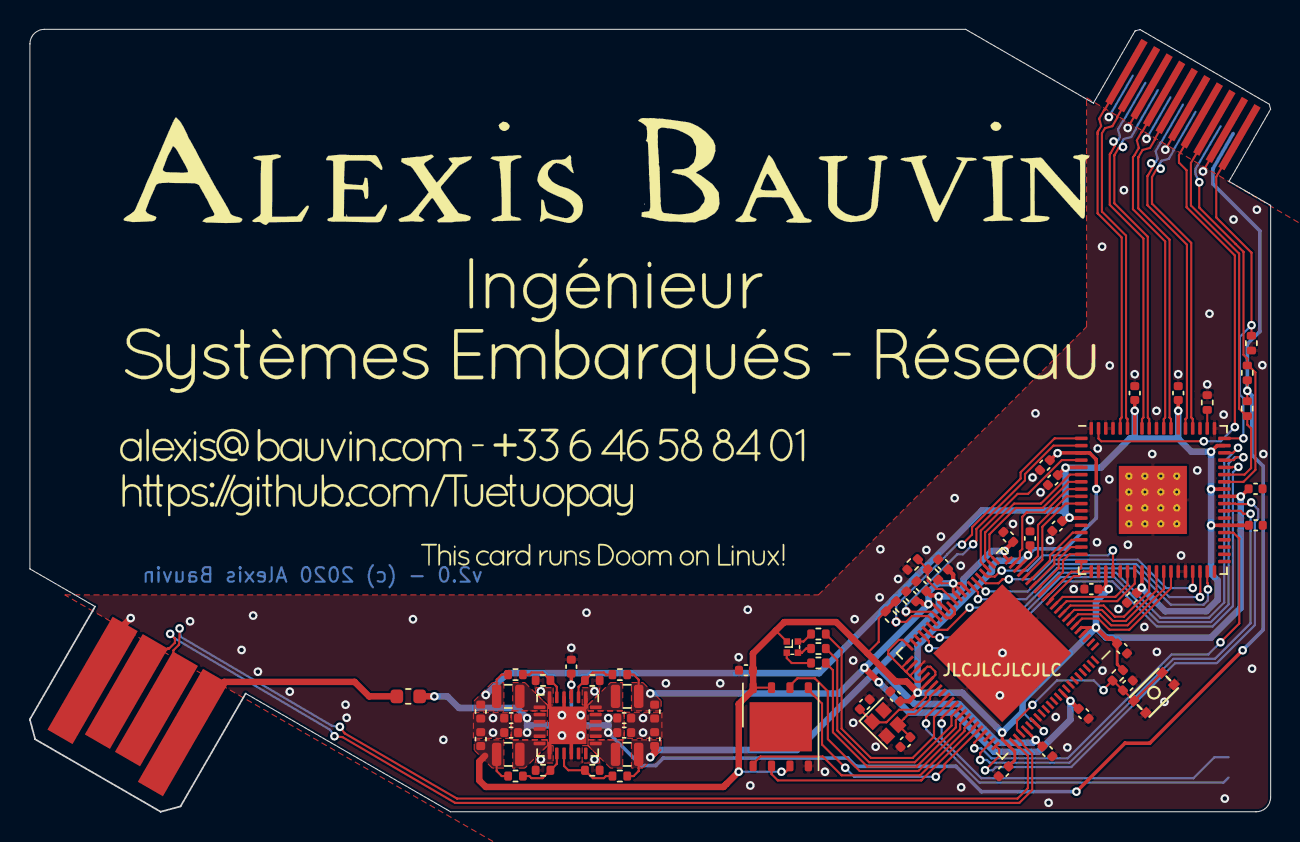
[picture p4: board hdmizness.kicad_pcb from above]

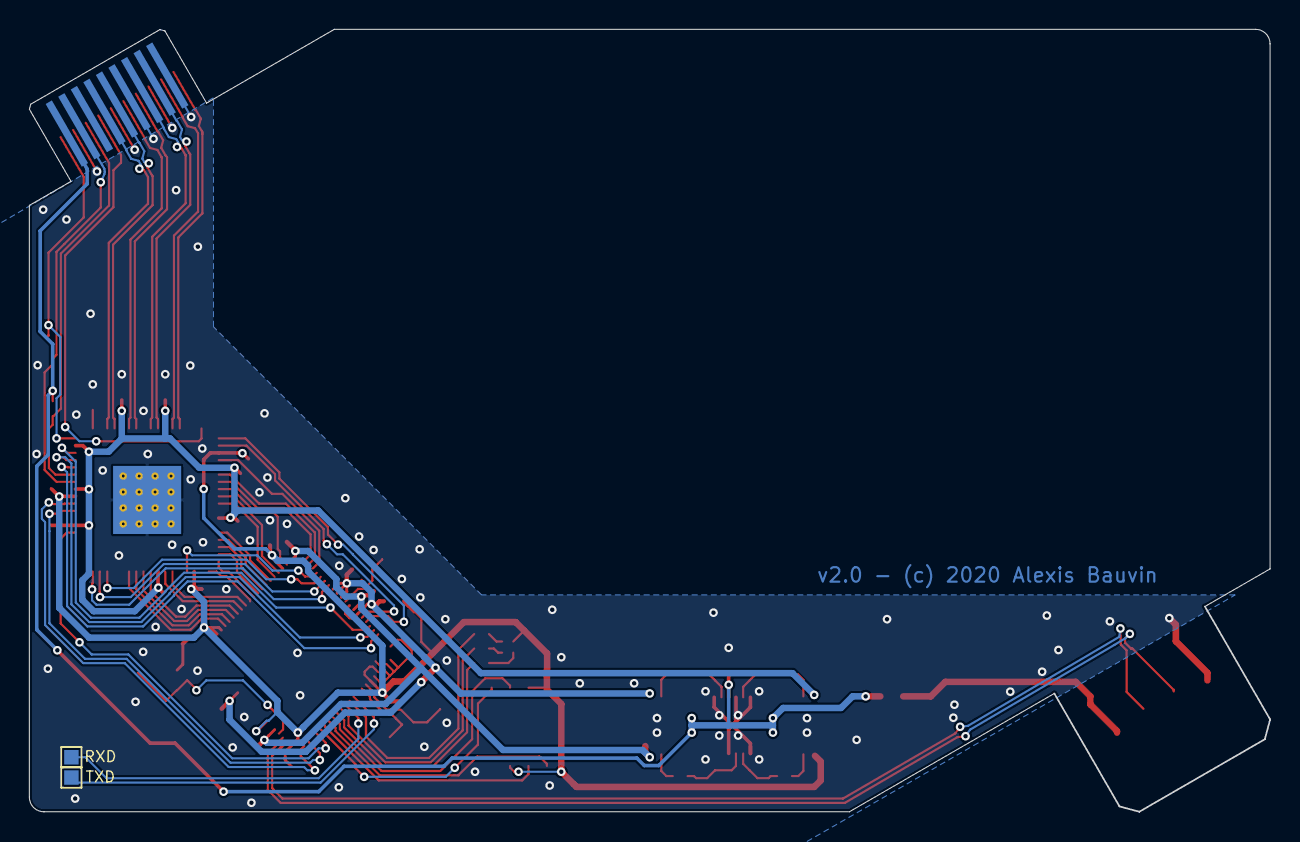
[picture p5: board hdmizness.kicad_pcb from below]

Board: 2 copper layers, 85.6 x 54.0 mm, 69 parts (2 on the bottom side), 76 nets.

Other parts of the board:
Ref**: Val**; card_front

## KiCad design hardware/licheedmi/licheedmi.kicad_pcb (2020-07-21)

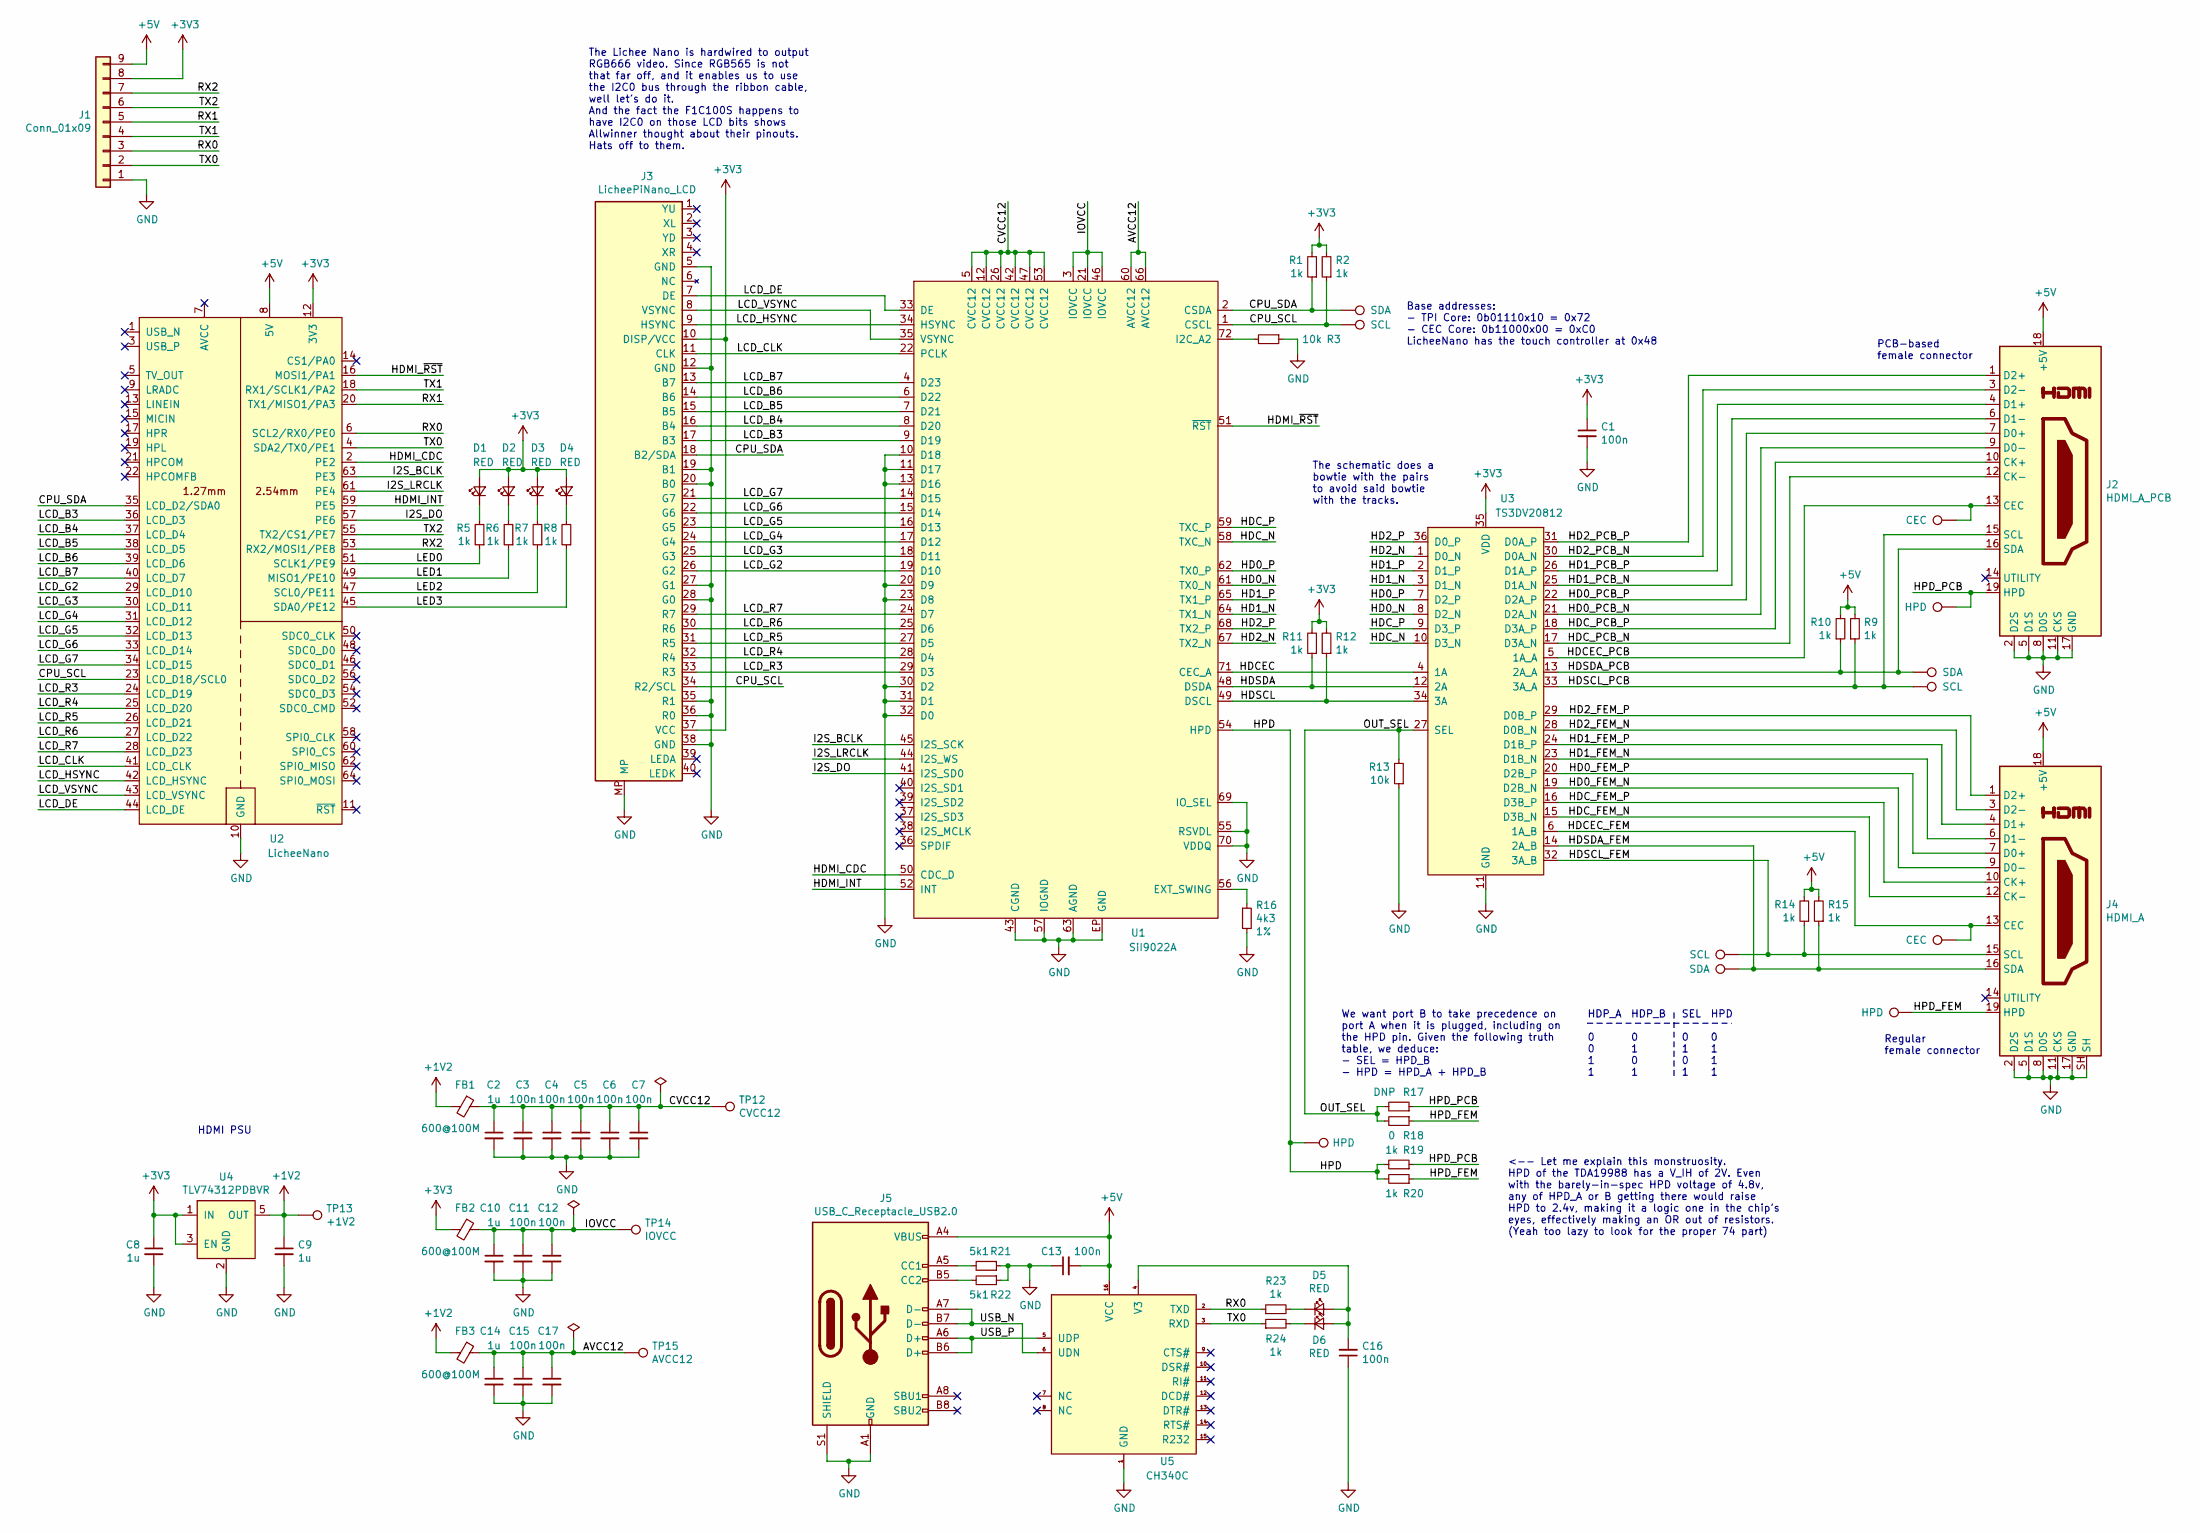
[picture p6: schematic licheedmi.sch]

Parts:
C1, C3, C4, C5, C6, C7, C11, C12, C13, C15, C16, C17: 100n; C_0603_1608Metric; MFR P/N CL10B104KB8NNNC; LCSC P/N C1591
C2, C8, C9, C10, C14: 1u; C_0603_1608Metric; MFR P/N CL10B105KP8NNNC; LCSC P/N C95843
D1, D2, D3, D4, D5, D6: RED; LED_0603_1608Metric; MFR P/N LTST-C193KRKT-5A; LCSC P/N C157741
FB1, FB2, FB3: 600@100M; L_0603_1608Metric; MFR P/N MMZ1608Y601BTA00; LCSC P/N C136491
J1: Conn_01x09; PinHeader_1x09_P2.54mm_Vertical; MFR P/N A2541WV-9P; LCSC P/N C225484
J2: HDMI_A_PCB
J3: LicheePiNano_LCD; Hirose_FH12-40S-0.5SH_1x40-1MP_P0.50mm_Horizontal; MFR P/N FH12-40S-0.5SH(55); LCSC P/N C202114
J4: HDMI_A; Boomelec_HDMI-001; MFR P/N HDMI-001; LCSC P/N C138388
J5: USB_C_Receptacle_USB2.0; USB_C_Receptacle_Palconn_UTC16-G; MFR P/N TYPE-C-31-M-12; LCSC P/N C165948
R1, R2, R5, R6, R7, R8, R9, R10, R11, R12, R14, R15, R19, R20, R23, R24: 1k; R_0603_1608Metric; MFR P/N SY0603JN1KP; LCSC P/N C380759
R3, R13: 10k; R_0603_1608Metric; MFR P/N RC0603FR-0710KL; LCSC P/N C98220
R16: 4k3; R_0603_1608Metric; Tolerance 1%; MFR P/N 0603WAF4301T5E; LCSC P/N C23159
R17: DNP; R_0603_1608Metric
R18: 0; R_0603_1608Metric; MFR P/N WR06X000PTL; LCSC P/N C132607
R21, R22: 5k1; R_0603_1608Metric; MFR P/N RS-03K5101FT; LCSC P/N C156350
TP1, TP5: CEC; TestPoint_Pad_D1.0mm
TP2, TP6, TP10: SCL; TestPoint_Pad_D1.0mm
TP3, TP7, TP11: SDA; TestPoint_Pad_D1.0mm
TP4, TP8, TP9: HPD; TestPoint_Pad_D1.0mm
TP12: CVCC12; TestPoint_Pad_D1.0mm
TP13: +1V2; TestPoint_Pad_D1.0mm
TP14: IOVCC; TestPoint_Pad_D1.0mm
TP15: AVCC12; TestPoint_Pad_D1.0mm
U1: SiI9022A; QFN-72-1EP_10x10mm_P0.5mm_EP4.7x4.7mm_ThermalVias; MFR P/N SII9022ACNU; LCSC P/N C369565
U2: LicheeNano; MFR P/N C35445; LCSC P/N C35445
U3: TS3DV20812; QFN-36-1EP_6x6mm_P0.5mm_EP4.1x4.1mm; MFR P/N TS3DV20812RHHR; LCSC P/N C130083
U4: TLV74312PDBVR; TSOT-23-5; MFR P/N TLV74312PDBVR; LCSC P/N C485149
U5: CH340C; SOIC-16_3.9x9.9mm_P1.27mm; MFR P/N CH340C; LCSC P/N C84681

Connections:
+1V2: C9.1, FB1.2, FB3.2, TP13.1, U4.5 (OUT)
+3V3: C1.1, C8.1, D1.2 (A), D2.2 (A), D3.2 (A), D4.2 (A), FB2.2, J1.8, J3.10 (DISP/VCC), J3.37 (VCC), R1.2, R2.2, R11.2, R12.2, U2.12 (3V3), U3.35 (VDD), U4.1 (IN), U4.3 (EN)
+5V: C13.2, J1.9, J2.18 (+5V), J4.18 (+5V), J5.A4 (VBUS), J5.A9 (VBUS), J5.B4 (VBUS), J5.B9 (VBUS), R9.2, R10.2, R14.2, R15.2, U2.8 (5V), U5.16 (VCC)
/AVCC12: C14.1, C15.1, C17.1, FB3.1, TP15.1, U1.60 (AVCC12), U1.66 (AVCC12)
/CPU_SCL: J3.34 (R2/SCL), R2.1, TP10.1, U1.1 (CSCL), U2.23 (LCD_D18/SCL0)
/CPU_SDA: J3.18 (B2/SDA), R1.1, TP11.1, U1.2 (CSDA), U2.35 (LCD_D2/SDA0)
/CVCC12: C2.1, C3.1, C4.1, C5.1, C6.1, C7.1, FB1.1, TP12.1, U1.5 (CVCC12), U1.12 (CVCC12), U1.26 (CVCC12), U1.42 (CVCC12), U1.47 (CVCC12), U1.53 (CVCC12)
/HD0_FEM_N: J4.9 (D0-), U3.19 (D2B_N)
/HD0_FEM_P: J4.7 (D0+), U3.20 (D2B_P)
/HD0_N: U1.61 (TX0_N), U3.8 (D2_N)
/HD0_P: U1.62 (TX0_P), U3.7 (D2_P)
/HD0_PCB_N: J2.9 (D0-), U3.21 (D2A_N)
/HD0_PCB_P: J2.7 (D0+), U3.22 (D2A_P)
/HD1_FEM_N: J4.6 (D1-), U3.23 (D1B_N)
/HD1_FEM_P: J4.4 (D1+), U3.24 (D1B_P)
/HD1_N: U1.64 (TX1_N), U3.3 (D1_N)
/HD1_P: U1.65 (TX1_P), U3.2 (D1_P)
/HD1_PCB_N: J2.6 (D1-), U3.25 (D1A_N)
/HD1_PCB_P: J2.4 (D1+), U3.26 (D1A_P)
/HD2_FEM_N: J4.3 (D2-), U3.28 (D0B_N)
/HD2_FEM_P: J4.1 (D2+), U3.29 (D0B_P)
/HD2_N: U1.67 (TX2_N), U3.1 (D0_N)
/HD2_P: U1.68 (TX2_P), U3.36 (D0_P)
/HD2_PCB_N: J2.3 (D2-), U3.30 (D0A_N)
/HD2_PCB_P: J2.1 (D2+), U3.31 (D0A_P)
/HDCEC: U1.71 (CEC_A), U3.4 (1A)
/HDCEC_FEM: J4.13 (CEC), TP5.1, U3.6 (1A_B)
/HDCEC_PCB: J2.13 (CEC), TP1.1, U3.5 (1A_A)
/HDC_FEM_N: J4.12 (CK-), U3.15 (D3B_N)
/HDC_FEM_P: J4.10 (CK+), U3.16 (D3B_P)
/HDC_N: U1.58 (TXC_N), U3.10 (D3_N)
/HDC_P: U1.59 (TXC_P), U3.9 (D3_P)
/HDC_PCB_N: J2.12 (CK-), U3.17 (D3A_N)
/HDC_PCB_P: J2.10 (CK+), U3.18 (D3A_P)
/HDMI_CDC: U1.50 (CDC_D), U2.2 (PE2)
/HDMI_INT: U1.52 (INT), U2.59 (PE5)
/HDMI_~RST: U1.51 (~RST), U2.16 (MOSI1/PA1)
/HDSCL: R12.1, U1.49 (DSCL), U3.34 (3A)
/HDSCL_FEM: J4.15 (SCL), R14.1, TP6.1, U3.32 (3A_B)
/HDSCL_PCB: J2.15 (SCL), R9.1, TP2.1, U3.33 (3A_A)
/HDSDA: R11.1, U1.48 (DSDA), U3.12 (2A)
/HDSDA_FEM: J4.16 (SDA), R15.1, TP7.1, U3.14 (2A_B)
/HDSDA_PCB: J2.16 (SDA), R10.1, TP3.1, U3.13 (2A_A)
/HPD: R19.2, R20.2, TP9.1, U1.54 (HPD)
/HPD_FEM: J4.19 (HPD), R18.1, R20.1, TP8.1
/HPD_PCB: J2.19 (HPD), R17.1, R19.1, TP4.1
/I2S_BCLK: U1.45 (I2S_SCK), U2.63 (PE3)
/I2S_DO: U1.41 (I2S_SD0), U2.57 (PE6)
/I2S_LRCLK: U1.44 (I2S_WS), U2.61 (PE4)
/IOVCC: C10.1, C11.1, C12.1, FB2.1, TP14.1, U1.3 (IOVCC), U1.21 (IOVCC), U1.46 (IOVCC)
/LCD_B3: J3.17 (B3), U1.9 (D19), U2.36 (LCD_D3)
/LCD_B4: J3.16 (B4), U1.8 (D20), U2.37 (LCD_D4)
/LCD_B5: J3.15 (B5), U1.7 (D21), U2.38 (LCD_D5)
/LCD_B6: J3.14 (B6), U1.6 (D22), U2.39 (LCD_D6)
/LCD_B7: J3.13 (B7), U1.4 (D23), U2.40 (LCD_D7)
/LCD_CLK: J3.11 (CLK), U1.22 (PCLK), U2.41 (LCD_CLK)
/LCD_DE: J3.7 (DE), U1.33 (DE), U2.44 (LCD_DE)
/LCD_G2: J3.26 (G2), U1.19 (D10), U2.29 (LCD_D10)
/LCD_G3: J3.25 (G3), U1.18 (D11), U2.30 (LCD_D11)
/LCD_G4: J3.24 (G4), U1.17 (D12), U2.31 (LCD_D12)
/LCD_G5: J3.23 (G5), U1.16 (D13), U2.32 (LCD_D13)
/LCD_G6: J3.22 (G6), U1.15 (D14), U2.33 (LCD_D14)
/LCD_G7: J3.21 (G7), U1.14 (D15), U2.34 (LCD_D15)
/LCD_HSYNC: J3.9 (HSYNC), U1.34 (HSYNC), U2.42 (LCD_HSYNC)
/LCD_R3: J3.33 (R3), U1.29 (D3), U2.24 (LCD_D19)
/LCD_R4: J3.32 (R4), U1.28 (D4), U2.25 (LCD_D20)
/LCD_R5: J3.31 (R5), U1.27 (D5), U2.26 (LCD_D21)
/LCD_R6: J3.30 (R6), U1.25 (D6), U2.27 (LCD_D22)
/LCD_R7: J3.29 (R7), U1.24 (D7), U2.28 (LCD_D23)
/LCD_VSYNC: J3.8 (VSYNC), U1.35 (VSYNC), U2.43 (LCD_VSYNC)
/LED0: R5.1, U2.51 (SCLK1/PE9)
/LED1: R6.1, U2.49 (MISO1/PE10)
/LED2: R7.1, U2.47 (SCL0/PE11)
/LED3: R8.1, U2.45 (SDA0/PE12)
/OUT_SEL: R13.2, R17.2, R18.2, U3.27 (SEL)
/RX0: J1.3, R23.1, U2.6 (SCL2/RX0/PE0), U5.2 (TXD)
/RX1: J1.5, U2.20 (TX1/MISO1/PA3)
/RX2: J1.7, U2.53 (RX2/MOSI1/PE8)
/TX0: J1.2, R24.1, U2.4 (SDA2/TX0/PE1), U5.3 (RXD)
/TX1: J1.4, U2.18 (RX1/SCLK1/PA2)
/TX2: J1.6, U2.55 (TX2/CS1/PE7)
/USB_N: J5.A7 (D-), J5.B7 (D-), U5.6 (UDN)
/USB_P: J5.A6 (D+), J5.B6 (D+), U5.5 (UDP)
GND: C1.2, C2.2, C3.2, C4.2, C5.2, C6.2, C7.2, C8.2, C9.2, C10.2, C11.2, C12.2, C13.1, C14.2, C15.2, C16.1, C17.2, J1.1, J2.2 (D2S), J2.5 (D1S), J2.8 (D0S), J2.11 (CKS), J2.17 (GND), J3.5 (GND), J3.12 (GND), J3.19 (B1), J3.20 (B0), J3.27 (G1), J3.28 (G0), J3.35 (R1), J3.36 (R0), J3.38 (GND), J3.MP, J4.2 (D2S), J4.5 (D1S), J4.8 (D0S), J4.11 (CKS), J4.17 (GND), J4.SH, J5.A1 (GND), J5.A12 (GND), J5.B1 (GND), J5.B12 (GND), J5.S1 (SHIELD), R3.1, R13.1, R16.2, R21.1, R22.1, U1.10 (D18), U1.11 (D17), U1.13 (D16), U1.20 (D9), U1.23 (D8), U1.30 (D2), U1.31 (D1), U1.32 (D0), U1.43 (CGND), U1.55 (RSVDL), U1.57 (IOGND), U1.63 (AGND), U1.69 (IO_SEL), U1.70 (VDDQ), U1.EP (GND), U2.10 (GND), U3.11 (GND), U4.2 (GND), U5.1 (GND)
unnamed: C16.2, D5.2 (A), D6.2 (A), U5.4 (V3)
unnamed: D1.1 (K), R5.2
unnamed: D2.1 (K), R6.2
unnamed: D3.1 (K), R7.2
unnamed: D4.1 (K), R8.2
unnamed: D5.1 (K), R23.2
unnamed: D6.1 (K), R24.2
unnamed: J5.A5 (CC1), R21.2
unnamed: J5.B5 (CC2), R22.2
unnamed: R3.2, U1.72 (I2C_A2)
unnamed: R16.1, U1.56 (EXT_SWING)

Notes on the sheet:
Base addresses: - TPI Core: 0b01110x10 = 0x72 - CEC Core: 0b11000x00 = 0xC0 LicheeNano has the touch controller at 0x48
The schematic does a bowtie with the pairs to avoid said bowtie with the tracks.
PCB-based female connector
Regular female connector
HDMI PSU
We want port B to take precedence on port A when it is plugged, including on the HPD pin. Given the following truth table, we deduce: - SEL = HPD_B - HPD = HPD_A + HPD_B
HDP_A 0 0 1 1
HDP_B 0 1 0 1
SEL 0 1 0 1
HPD 0 1 1 1
<-- Let me explain this monstruosity. HPD of the TDA19988 has a V_IH of 2V. Even with the barely-in-spec HPD voltage of 4.8v, any of HPD_A or B getting there would raise HPD to 2.4v, making it a logic one in the chip's eyes, effectively making an OR out of resistors. (Yeah too lazy to look for the 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
The Lichee Nano is hardwired to output RGB666 video. Since RGB565 is not that far off, and it enables us to use the I2C0 bus through the ribbon cable, well let's do it. And the fact the F1C100S happens to have I2C0 on those LCD bits shows Allwinner thought about their pinouts. Hats off to them.

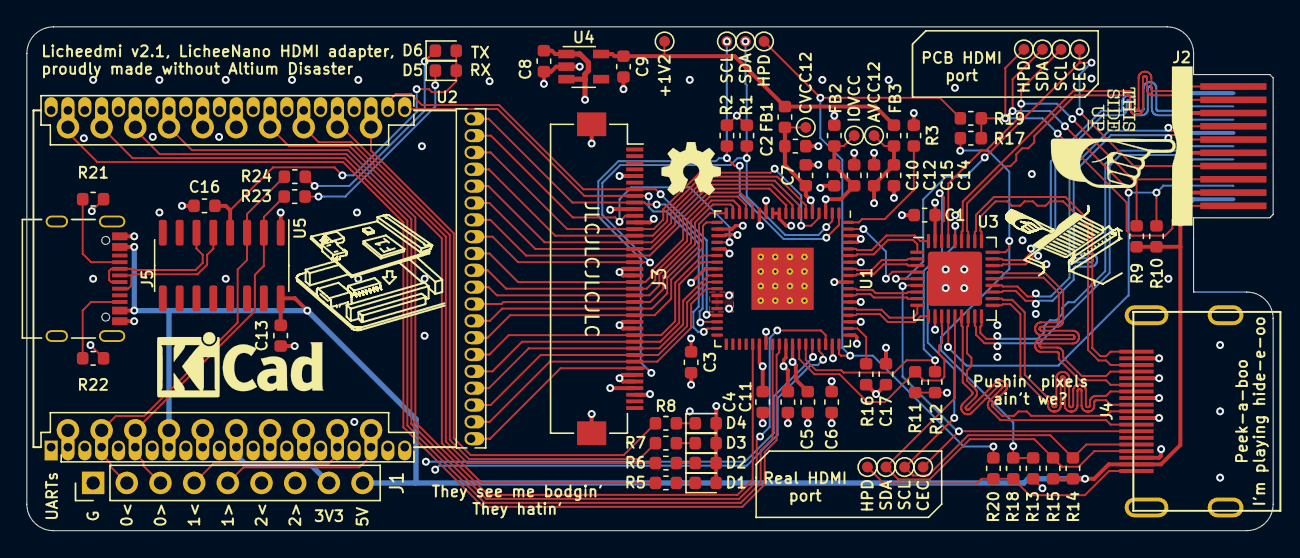
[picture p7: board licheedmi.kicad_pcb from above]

Board: 4 copper layers, 94.0 x 38.0 mm, 74 parts (0 on the bottom side), 95 nets.

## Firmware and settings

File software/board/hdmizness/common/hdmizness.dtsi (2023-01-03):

/*
 * Copyright (C) 2020 Tuetuopay <tuetuopay@me.com>
 *
 * SPDX-License-Identifier: (GPL-2.0+ OR X11)
 */

/dts-v1/;
#include "suniv-f1c100s.dtsi"
#include <dt-bindings/gpio/gpio.h>

/ {
	model = "HDMIzness";
	compatible = "tuetuopay,hdmizness", "allwinner,suniv-f1c100s";

	aliases {
		serial0 = &uart0;
		spi0 = &spi0;
	};

	chosen {
		stdout-path = "serial0:115200n8";
	};

	leds {
		compatible = "gpio-leds";
		pinctrl-names = "default";
		pinctrl-0 = <&led_pins>;

		red {
			label = "red";
			gpios = <&pio 5 3 GPIO_ACTIVE_LOW>;
			default-state = "on";
		};

		green {
			label = "green";
			gpios = <&pio 5 1 GPIO_ACTIVE_LOW>;
			default-state = "on";
		};

		blue {
			label = "blue";
			gpios = <&pio 5 0 GPIO_ACTIVE_LOW>;
			default-state = "on";
		};
	};

	reg_vcc3v3: vcc3v3 {
		compatible = "regulator-fixed";
		regulator-name = "vcc3v3";
		regulator-min-microvolt = <3300000>;
		regulator-max-microvolt = <3300000>;
	};
};

&pio {
	uart0_pf_pins: uart0-pf-pins {
		pins = "PF2", "PF4";
		function = "uart0";
	};

	i2s_pa_pins: i2s-pa-pins {
		pins = "PA0", "PA1", "PA3";
		function = "i2s";
	};

	led_pins: led-pins {
		pins = "PF0", "PF1", "PF3";
		function = "gpio_out";
	};
};

&otg_sram {
	status = "okay";
};

&spi0 {
	pinctrl-names = "default";
	pinctrl-0 = <&spi0_pc_pins>;
	status = "okay";

	flash@0 {
		#address-cells = <1>;
		#size-cells = <1>;
		compatible = "winbond,w25q128", "jedec,spi-nor";
		reg = <0>;
		spi-max-frequency = <40000000>;

		partitions {
			compatible = "fixed-partitions";
			#address-cells = <1>;
			#size-cells = <1>;

			partition@0 {
				label = "u-boot";
				reg = <0x000000 0x80000>;
			};

			partition@110000 {
				label = "rootubi";
				reg = <0x80000 0xf80000>;
			};
		};
	};
};

&uart0 {
	pinctrl-names = "default";
	pinctrl-0 = <&uart0_pf_pins>;
	status = "okay";
};

&i2c0 {
	status = "okay";
};

&usb_otg {
	dr_mode = "peripheral";
	status = "okay";
};

&usbphy {
	usb0_id_det-gpio = <&pio 4 6 GPIO_ACTIVE_HIGH>; /* PE6 */
	status = "okay";
};

&be0 {
	status = "okay";
};

&de {
	status = "okay";
};

&tcon0 {
	pinctrl-names = "default";
	pinctrl-0 = <&lcd_rgb666_pins>;
	status = "okay";
};

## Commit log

2020-05-27 sch: Add LicheeNano LCD connector
2020-05-28 sch: Main video data path done
    [licheedmi.sch]
2020-05-28 Fix file permissions
    [licheedmi.sch]
2020-05-28 fp: Add LicheeNano footprint
2020-05-28 sch: Add HDMI 1.8V PSU
    [licheedmi.sch]
2020-05-29 sch: Add HPD handling
    [licheedmi.sch]
2020-05-29 fp: Add the star of the show: the PCB-based HDMI connector
2020-05-29 fp: Add "regular" female HDMI connector
2020-05-29 sch: Misc touches
    [licheedmi.sch]
2020-05-29 fp: Center HDMI footprints
2020-05-29 sch: Add lots of testpoints
    [licheedmi.sch]
2020-05-29 sch: Part number assignment done
    [licheedmi.sch]
2020-05-29 sch: Add symbol for the PCB-based HDMI connector
    [licheedmi.sch]
2020-05-29 fp: Add min width pcb hdmi keepout
2020-05-29 pcb: Placement done
    [licheedmi.kicad_pcb, licheedmi.sch]
2020-05-29 pcb: Routing done
    [licheedmi.kicad_pcb]
2020-05-30 pcb: Add "this side up" symbol to PCB
    [licheedmi.kicad_pcb]
2020-06-01 pcb: Fix mistakenly rotated hdmi track
    [licheedmi.kicad_pcb]
2020-06-01 pcb: Length and skew tuned HDMI pairs
    [licheedmi.kicad_pcb]
2020-06-01 pcb: Changed layer 3 from +3V3 to GND
    [licheedmi.kicad_pcb]
2020-06-01 pcb: Add proper diff pair layer transition vias
    [licheedmi.kicad_pcb]
2020-06-02 fp: Add male HDMI plug 3D model to PCB HDMI connector
    [licheedmi.kicad_pcb]
2020-06-02 pcb: Add drawing to help with HDMI connector orientation
    [licheedmi.kicad_pcb]
2020-06-02 pcb: Move LEDs and add silkscreen stuff
    [licheedmi.kicad_pcb]
2020-06-02 sch, pcb: Add 3V3 and 5V headers
    [licheedmi.kicad_pcb, licheedmi.sch]
2020-06-02 pcb: Add OSHW logo
    [licheedmi.kicad_pcb]
2020-06-02 fp, pcb: Fix absolute 3D model path
    [licheedmi.kicad_pcb]
2020-06-03 pcb: Fix silk for testpads
    [licheedmi.kicad_pcb]
2020-06-04 sch: Draw wires rather than labels where wiring is straightforward
    [licheedmi.sch]
2020-06-04 *: Add USB-UART chip (CH340C)
    [licheedmi.kicad_pcb, licheedmi.sch]
2020-06-04 sch, pcb: Add UART0 activity LEDs
    [licheedmi.kicad_pcb, licheedmi.sch]
2020-06-04 pcb: Fix DRC issues
    [licheedmi.kicad_pcb]
2020-06-04 sch: Fix real ERC issues
    [licheedmi.sch]
2020-06-04 sch: Add missing P/N for USB-C connector
    [licheedmi.sch]
2020-06-04 Add FPC connector 3D model
    [licheedmi.kicad_pcb, licheedmi.sch]
2020-06-05 sym, fp, sch: Fix LicheeNano and LCD connector being flipped
    [licheedmi.sch]
2020-06-05 pcb: Reroute PCB following footprint flip
    Bowtie and complicated via thingies are gone now \o/
    [licheedmi.kicad_pcb, licheedmi.sch]
2020-06-05 pcb: Add Lichee pinout on silk and stich grounds
    [licheedmi.kicad_pcb]
2020-06-05 pcb: Add lichee orientation to silk
    [licheedmi.kicad_pcb]
2020-06-05 pcb: Fix solder mask clearance and min width
    [licheedmi.kicad_pcb]
2020-06-05 pcb: Fix JLC string
    JLCPCB requires the string "JLCJLCJLCJLC" to be specified to control
    where they'll put the order number. One of the four JLC was missing...
    [licheedmi.kicad_pcb]
2020-07-01 sch: Wire I2S
    [licheedmi.sch]
2020-07-01 pcb: Wire I2S signals
    [licheedmi.kicad_pcb]
2020-07-01 licheedmi: Release v1.1
    [licheedmi.kicad_pcb]
2020-07-01 doc: Add LicheeNano schematic
2020-07-01 sch: Replace TDA19988 with SiI9022A (wip)
    [licheedmi.sch]
2020-07-01 lib: Tweak SiI9022A pin positions on symbol
2020-07-01 sch: Use 1.2V LDO for SiI and fix auxilary signals
    [licheedmi.sch]
2020-07-01 sch: Add extra decoupling cap on AVCC line
    [licheedmi.sch]
2020-07-01 pcb: Route SiI9022A
    [licheedmi.kicad_pcb]
2020-07-01 fp: Add 3D model for QFN72 used by SiI9022A
    [licheedmi.kicad_pcb]
2020-07-01 sch: Add missing C17 cap
    [licheedmi.sch]
2020-07-01 Release licheedmi v2.0
    [licheedmi.kicad_pcb]
2020-07-21 pcb: Refill copper zones
    Because zones were not properly refilled, many signals and power rails
    were shorted to ground internally, meaning no bodge possibility.
    [licheedmi.kicad_pcb]
2020-07-21 Release licheedmi v2.1
    [licheedmi.kicad_pcb]
2020-11-14 lib: Add F1C100s symbol
    [hdmizness.kicad_pcb, hdmizness.sch]
2020-11-14 fp: Add F1C100s footprint
2020-11-14 lib: Add FC-B1010RGBT-HG RGB LED
2020-11-14 lib: Add PCB-based USB connector
2020-11-14 hdmizness: Add schematic first draft
    [hdmizness.sch]
2020-11-14 hdmizness: Use smaller components
    [hdmizness.sch]
2020-11-14 hdmizness: Routing done
    [hdmizness.kicad_pcb, hdmizness.sch]
2020-11-14 pcb: Add front design
    [hdmizness.kicad_pcb]
2020-11-14 hdmizness: Add board revision hard straps
    [hdmizness.kicad_pcb, hdmizness.sch]
2020-11-15 hdmizness/sch: Add component MFR P/N and LCSC P/N
    [hdmizness.sch]
2020-11-15 lib: Add missing F1C100s 3D model
    [hdmizness.kicad_pcb]
2020-11-15 hdmizness: pcb: Add JLCPCB-specific string to set order number posision
    [hdmizness.kicad_pcb]
2020-11-15 hdmizness: Redo HDMI part with SiI9022A
    Since I have a stock of 25 of both ICs...
    [hdmizness.kicad_pcb, hdmizness.sch]
2021-03-15 soft: Add first working, booting version
    This includes basic Buildroot, U-Boot and Linux configs to get Linux
    booting on the board
    [genimage.cfg]
2021-03-25 software: Fix USB det pin in dts
    [hdmizness.dtsi]
2021-04-14 software: Lighten up config to free up flash space
    I doubt the full vim runtime is terribly useful on this card... I even
    doubt vim itself is useful...
    [genimage.cfg]
2022-04-20 software: Add sample files in board overlay

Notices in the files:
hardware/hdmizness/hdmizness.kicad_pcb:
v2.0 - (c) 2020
